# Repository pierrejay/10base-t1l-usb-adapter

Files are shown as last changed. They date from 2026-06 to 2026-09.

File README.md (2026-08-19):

# Single Pair Ethernet 10BASE-T1L USB adapter

A USB ↔ SPE 10BASE-T1L adapter: plug it into any Linux host and get a
standard network interface that speaks Ethernet over a single twisted pair
(long-reach, up to ~1 km, 10 Mbit/s full-duplex). An easy way to give
a laptop, a Raspberry Pi, or an embedded SoC an SPE T1L port for bring-up and
diagnostics.

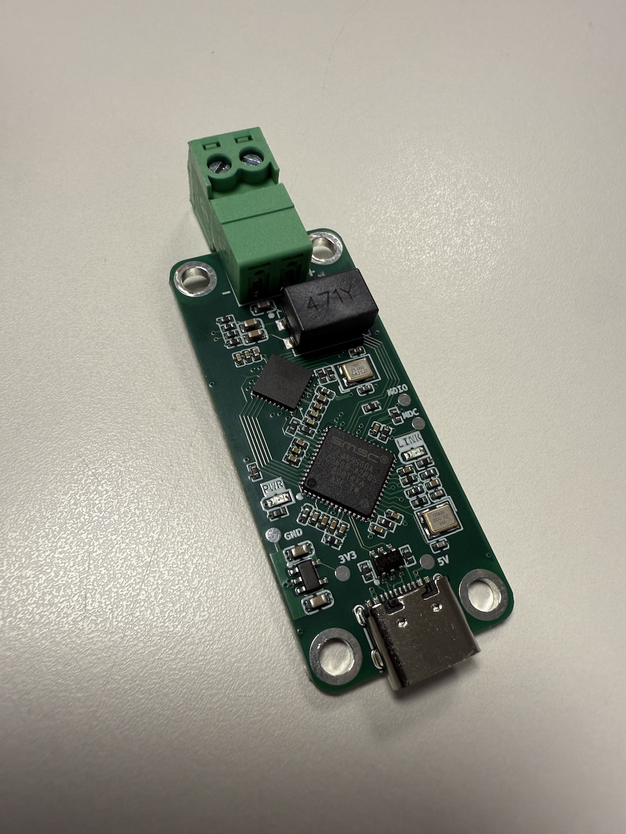
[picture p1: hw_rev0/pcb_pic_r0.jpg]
T1L USB adapter PCB rev 0 — front


## Main components

| Part | Function | Datasheet |
|---|---|---|
| Microchip LAN9500A | USB 2.0 ↔ Ethernet MAC | [product page](https://www.microchip.com/en-us/product/lan9500a) |
| TI DP83TD510E | 10BASE-T1L PHY | [product page](https://www.ti.com/product/DP83TD510E) |

The LAN9500A runs in external PHY (MII) mode: its internal 100M PHY is
bypassed and the MII bus drives the DP83TD510E.

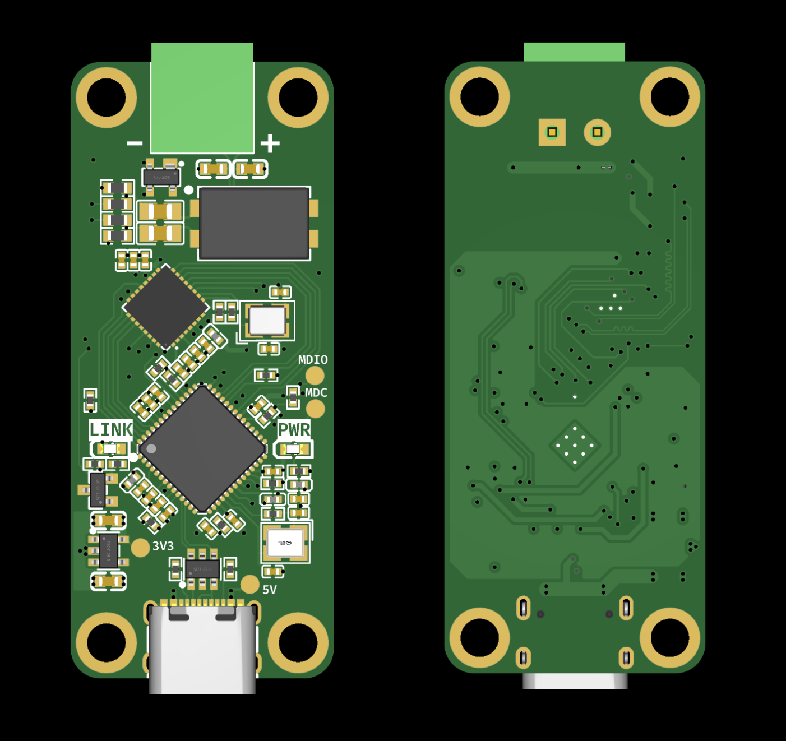
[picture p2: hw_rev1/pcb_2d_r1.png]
T1L USB adapter PCB rev 1 — front and back


## Changelog - Rev 1

- Changed the SPE 24V TVS to a low-cap Ethernet part (`PESD2ETH-AX`) and moved it to
  the PHY side of the CMC for better DP83TD510E front-end protection.
- Updated the termination R/C parts to full 100 V-rated parts for better
  PoDL/cable-fault withstand margin.
- Reworked the cable-side routing, including a copper keepout under the cable
  area up to the CMC (NXP guidelines for UTP).
- Moved LINK LED control from the LAN9500A (unsupported in external PHY mode) to the DP83TD510E.
- Swapped PWR/LINK LED placement to simplify routing.
- Board size is now **51.5 × 22 mm** (Rev 0 was 50 × 22 mm).

## Enclosure

A 3D-printable case STEP model is provided for each of the hardware revisions. It needs a single ⌀2.5×8 mm flat head screw (Plastite or sheet metal/self-tapping screw) to attach the USB-side cap.

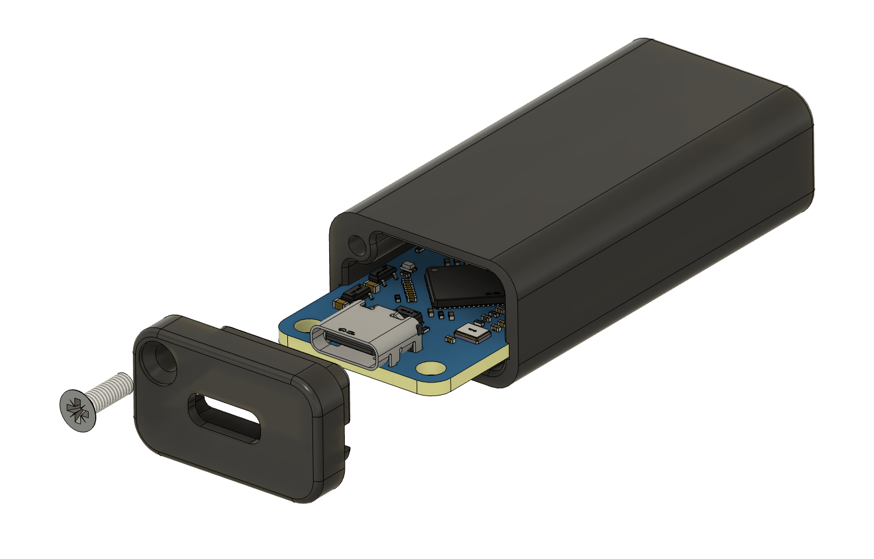
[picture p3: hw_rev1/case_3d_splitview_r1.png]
T1L USB adapter PCB rev 1 — 3D split view with case


## Fabrication

Turnkey at JLCPCB. Import the EasyEDA Pro project, then order PCB + assembly in one shot. 

Rev 1 is also provided as a KiCad project in [`hw_rev1/kicad/`](hw_rev1/kicad/) (KiCad v9.0.7).

**4-layer PCB**: select the `JLC04161H-3313` stackup. The impedance-sensitive 
nets (USB-C D±, the MII bus, the T1L pair) are designed against that specific stackup.

## How it appears to Linux

Two chips, two drivers:

| Chip | Role | Linux driver | Notes |
|---|---|---|---|
| Microchip LAN9500A | USB 2.0 Ethernet MAC | `smsc95xx` | In mainline since forever, same family as the Raspberry Pi's own NIC. Works out of the box. |
| TI DP83TD510E | 10BASE-T1L PHY | `dp83td510` | In mainline since Linux 5.19, but **not always enabled** by distro kernels. Without it the link won't come up. |

When you plug the dongle in, `smsc95xx` enumerates and creates an interface
(`eth0`, `eth1`, … called `ethN` below). The MDIO scan finds the DP83TD510E
at address 0 (PHY ID `0x2000.0181`). **The PHY driver must be present**, or the
PHY falls back to *Generic PHY* and the T1L link never establishes.

> Quick identity check: `lsusb` should show VID `0424` / PID `9e00`.

## OS / driver support

| Host | `smsc95xx` (MAC) | `dp83td510` (PHY) | What to do |
|---|---|---|---|
| **Recent Ubuntu / Debian** (kernel ≥ 6.x) | usually built-in | usually built-in | Works out of the box when the PHY driver is enabled. Cable test (`ethtool --cable-test`) is kernel/driver-version dependent. |
| **Raspberry Pi OS** (Bookworm, ~6.x) | built-in | **absent** on the tested image | Build the PHY driver via DKMS (see below). Validated on Pi 3B+ / 6.12. |
| **Embedded target** (Buildroot / Yocto) | enable `CONFIG_USB_NET_SMSC95XX` | enable `CONFIG_DP83TD510_PHY` | Confirmed working from kernel **6.1 up** with the right driver/config in the BSP. Cable-test support is version-dependent, see the note below. |

> **Cable test on embedded kernels: it depends.** `ethtool --cable-test` needs a
> recent enough `dp83td510`. The 6.1-era driver may predate it, but the driver has
> been updated upstream since, so whether it's there comes down to exactly what
> your BSP ships (YMMV; check case by case). Where it's missing, the TDR/ALCD
> sequence can be driven directly over MDIO instead of through `ethtool`.

### Enabling the PHY driver as DKMS

On stock Raspberry Pi OS (and any host whose kernel doesn't ship `dp83td510`),
build it out-of-tree as a DKMS module so it survives reboots and kernel
updates. See the [`install-dp83td510-dkms.sh`](install-dp83td510-dkms.sh) script
(tested on RPi 3B+, very likely working on RPi 4, TBC for RPi 5).

After installing, unplug and replug the dongle, the PHY binds at USB
enumeration. Then `dmesg | grep -i DP83TD510` should read
`... attached PHY driver` (not `Generic PHY`).

## Quick start - Bring up a link

10BASE-T1L is point-to-point: one end is **master** (drives the clock), the other
**slave**. The DP83TD510E supports BASE-T1 auto-negotiation (IEEE 802.3cg) and
the dongle defaults to **preferred slave** so against a gateway, switch or media
converter that is master, the roles resolve automatically and the dongle will
not try to take master.

On a managed host (NetworkManager, `dhcpcd`, `systemd-networkd`, ...), the
interface may already be up and configured when the dongle is plugged in. Check
first, then bring it up manually only if it is still down:

```sh
ip link show ethN
sudo ip link set ethN up   # only if the interface is still DOWN / unmanaged
ethtool ethN               # Link detected: yes, Speed 10Mb/s, Duplex Full
sudo dhclient ethN         # only if DHCP was not already handled
```

A working link reads `10baseT1L/Full` and `Link detected: yes`.

You only need to force a role when auto-negotiation can't settle it: two
dongles back to back (both default to slave), or a peer running with AN disabled
/ a fixed role you have to match:

```sh
sudo ethtool -s ethN master-slave forced-master   # or forced-slave, to match the peer
```

## Throughput sanity check

Bench test: `iperf3` between a Mac and a Linux target, through this dongle and a
WAGO 852-1705 gateway. TCP throughput is stable in both directions at about line
rate:

- **downlink:** ~9.4 Mbit/s effective, with 0 retransmits in the captured run.
- **uplink:** ~9.4 Mbit/s effective.

For a 10 Mbit/s T1L link, that's the expected ceiling once Ethernet/IP/TCP
overhead is counted.

## Diagnostics with stock tools

`ethtool` and [`phytool`](https://github.com/wkz/phytool) cover the essentials —
no project-specific software needed. `ethtool` ships with every distro; `phytool`
often isn't packaged (e.g. on Raspberry Pi OS), but it builds in seconds:

```sh
git clone https://github.com/wkz/phytool && make -C phytool
sudo cp phytool/phytool /usr/local/bin/   # or anywhere on your PATH
```

### Link, speed, master/slave

```sh
ethtool ethN
#   Speed: 10Mb/s
#   Duplex: Full
#   Supported link modes:   10baseT1L/Full
#   master-slave cfg: forced master      (or preferred slave)
#   Link detected: yes
```

### Reliable link status (PHY_STS)

The Clause-22 BMSR link bit is latch-low on this PHY and gives timing false
negatives. The robust source is the vendor `PHY_STS` register (Clause 22, reg
`0x10`), bit 0 = link up:

```sh
phytool read ethN/0/0x10        # bit0 set => link up
```

### Signal quality (SQI / MSE)

The DP83TD510E reports a Mean-Square-Error metric (MMD VEND2 `0x1F`, reg
`0xA85`); lower MSE = cleaner signal = higher SQI (0–7). Native Clause-45 access
returns `EOPNOTSUPP` on the `smsc95xx` MDIO bus, so read it the way the kernel
does, **Clause-22-indirect** via the MMD access registers (`0x0D`/`0x0E`):

```sh
phytool write ethN/0/0x0d 0x001f   # MMD_CTRL: function=address, devad=0x1F
phytool write ethN/0/0x0e 0x0a85   # MMD_DATA: register = MSE_DETECT
phytool write ethN/0/0x0d 0x401f   # MMD_CTRL: function=data, devad=0x1F
phytool read  ethN/0/0x0e          # -> MSE, e.g. 0x001b
```

Reference (good link, on the bench): MSE `0x001b` → SQI 7/7, SNR ≈ 35 dB. The
SQI thresholds live in the `dp83td510` driver / TI datasheet.

### Cable test (TDR / ALCD)

On a kernel whose `dp83td510` includes cable test (≥ 6.x):

```sh
ethtool --cable-test ethN
```

- **Link up** → ALCD reports cable **length**.
- **Link down** → TDR reports a **fault** (open / short) and a location.

> ⚠ **Distance is not trustworthy out of the box.** The fault *type* (open vs
> short) is reliable; the *distance* is raw and the kernel's ×100 scaling looks
> wrong at short range (it reports ~25 m for a meter-ish-long cable). Real distance
> needs per-cable calibration (TI app note SNLA364).

The raw-graph form (`--cable-test-tdr`) is not supported by this driver.

## License

Licensed under `CERN-OHL-P-2.0` (cf. LICENSE file)

© Pierre Jay 2026

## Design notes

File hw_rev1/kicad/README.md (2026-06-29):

# KiCad

This KiCad project was imported from EasyEDA and is maintained with KiCad v9.0.7.

EasyEDA 3D model files are not versioned here. They should be regenerated locally with `easyeda2kicad` and the sync helper.

## Restore 3D Models

Requirements:

- `easyeda2kicad` installed and available in `PATH`
- local central library in `~/Documents/KiCad/easyeda2kicad`

From this directory:

```bash
EASYEDA_LIBRARY="$HOME/Documents/KiCad/easyeda2kicad"

./sync_easyeda_models.py . \
  --library "$EASYEDA_LIBRARY" \
  --pull-footprint-models
```

The script copies only the required models into `EASYEDA_MODELS/`, applies known 3D alignment fixes, and fetches missing parts through `easyeda2kicad` when possible.

## After 3D Alignment Fixes

If a model is manually realigned in KiCad, push the correction back to the local library:

```bash
EASYEDA_LIBRARY="$HOME/Documents/KiCad/easyeda2kicad"

./sync_easyeda_models.py . \
  --library "$EASYEDA_LIBRARY" \
  --push-to-library
```

Other projects can then reuse those fixes with `--pull-footprint-models`.

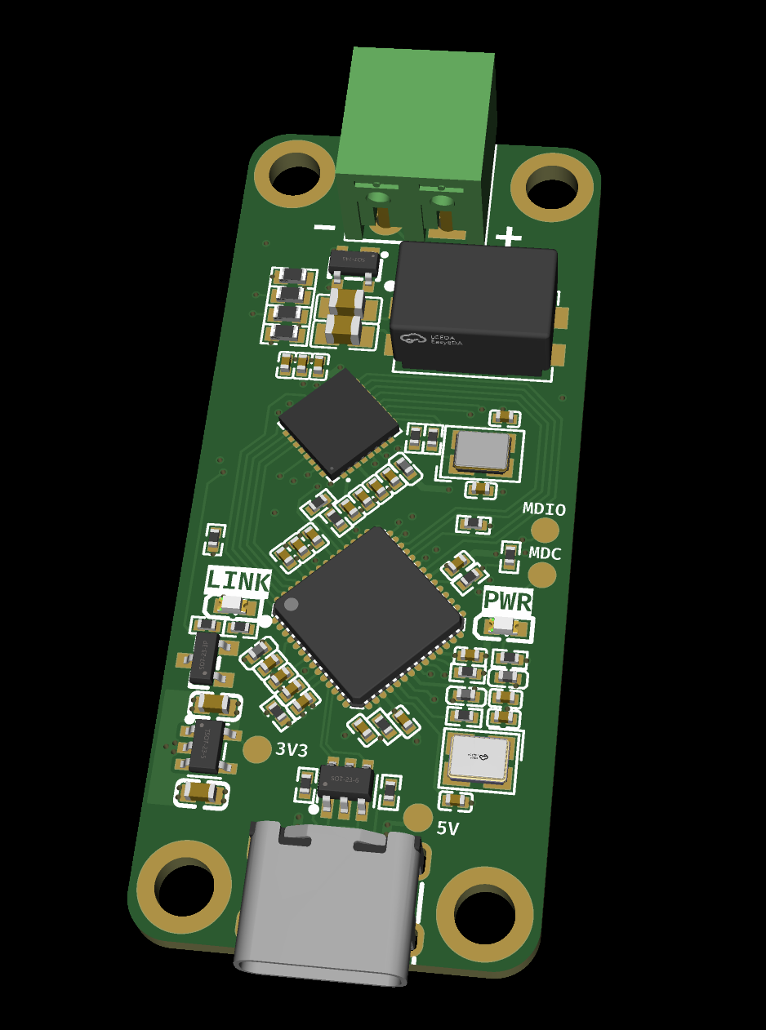
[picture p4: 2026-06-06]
hw_rev1/pcb_3d_r1.png

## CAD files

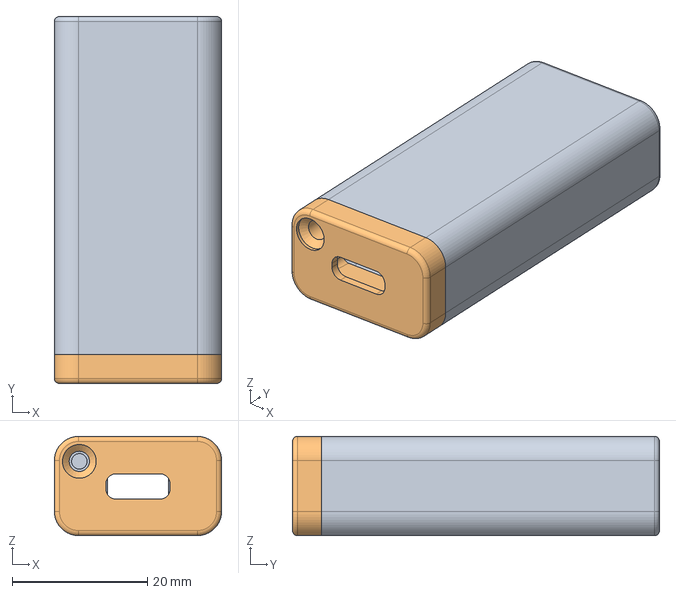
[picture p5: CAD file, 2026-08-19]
hw_rev1/spe-T1L_usb_adapter_case_r1.step
24.8 x 54.3 x 14.7 mm

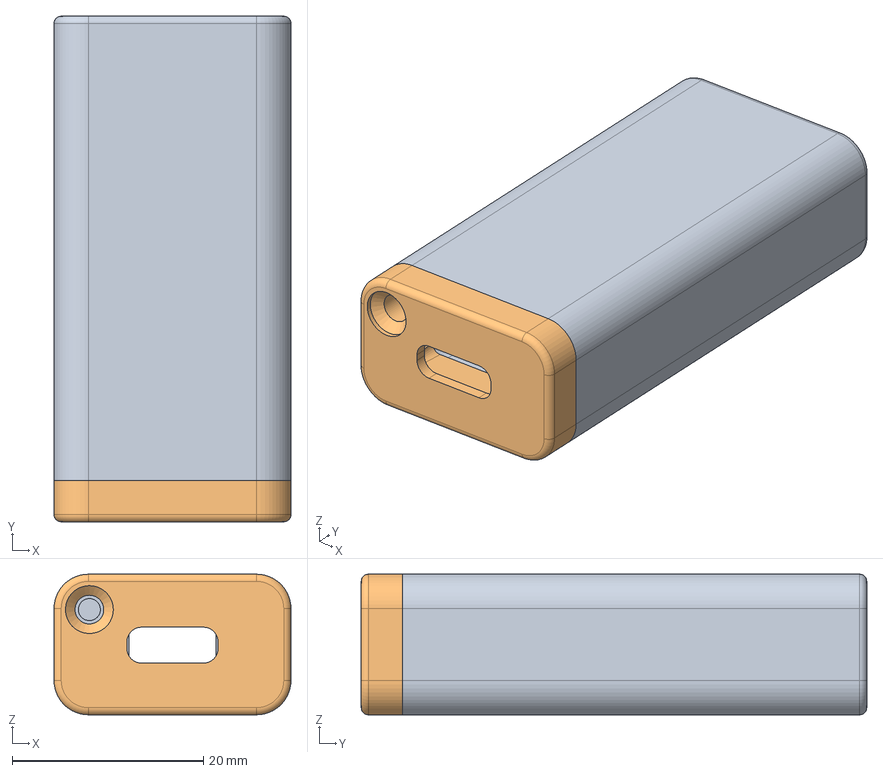
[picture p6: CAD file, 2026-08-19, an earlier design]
hw_rev0/spe-T1L_usb_adapter_case_r0.step
24.8 x 52.8 x 14.7 mm

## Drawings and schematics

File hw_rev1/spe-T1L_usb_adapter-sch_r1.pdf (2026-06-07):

# USB-Ethernet MAC

# SPE termination

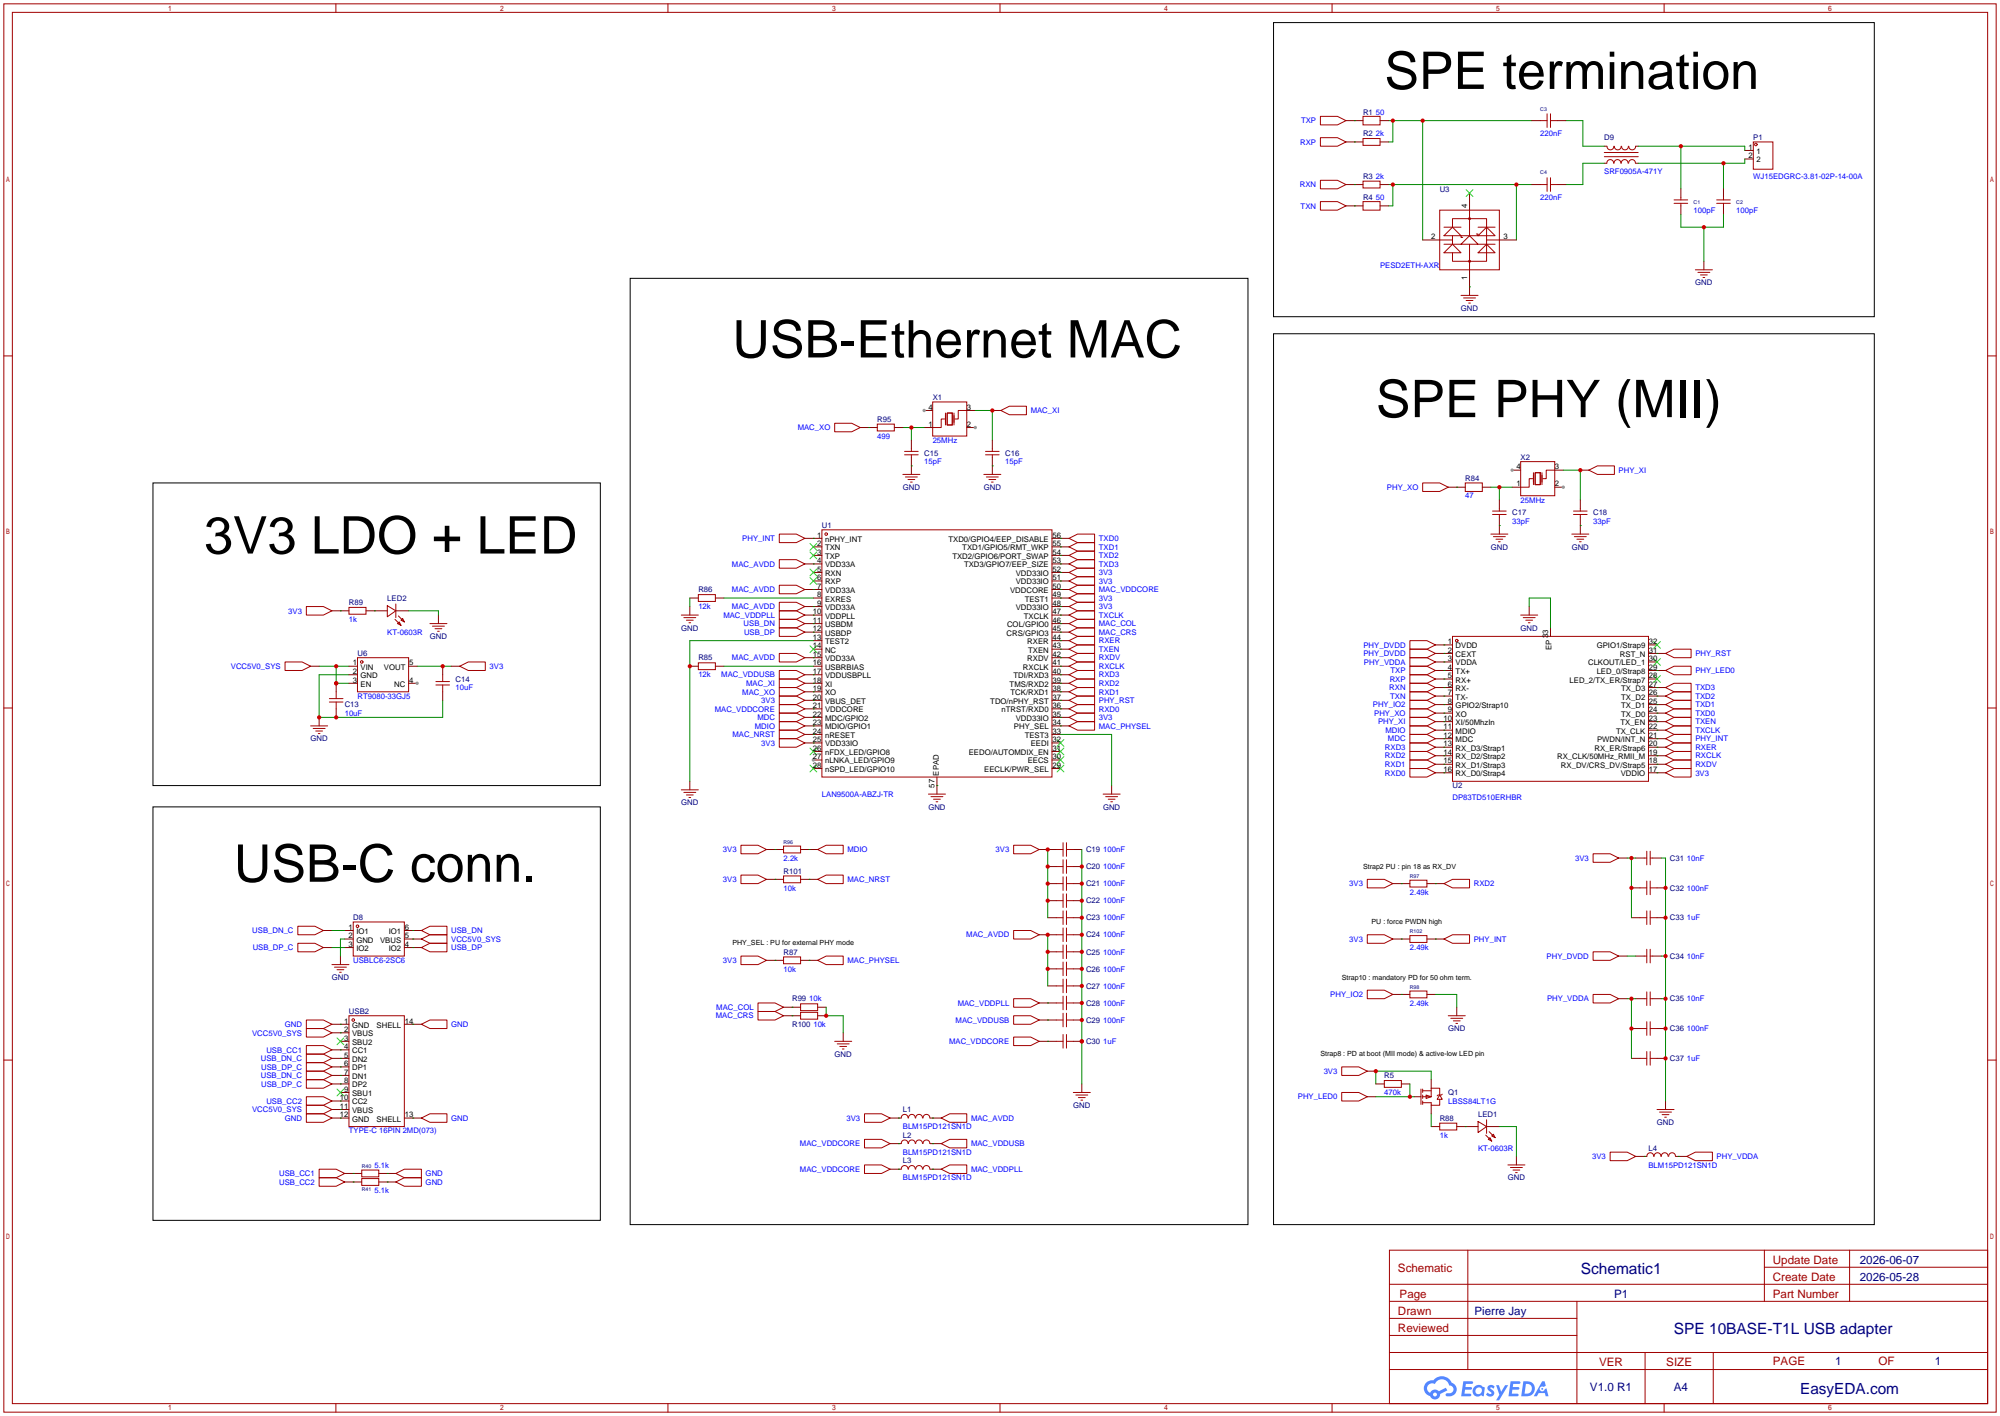
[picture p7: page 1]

PU : force PWDN high

PHY_SEL : PU for external PHY mode

Strap10 : mandatory PD for 50 ohm term.
PHY_IO2

Strap8 : PD at boot (MII mode) & active-low LED pin

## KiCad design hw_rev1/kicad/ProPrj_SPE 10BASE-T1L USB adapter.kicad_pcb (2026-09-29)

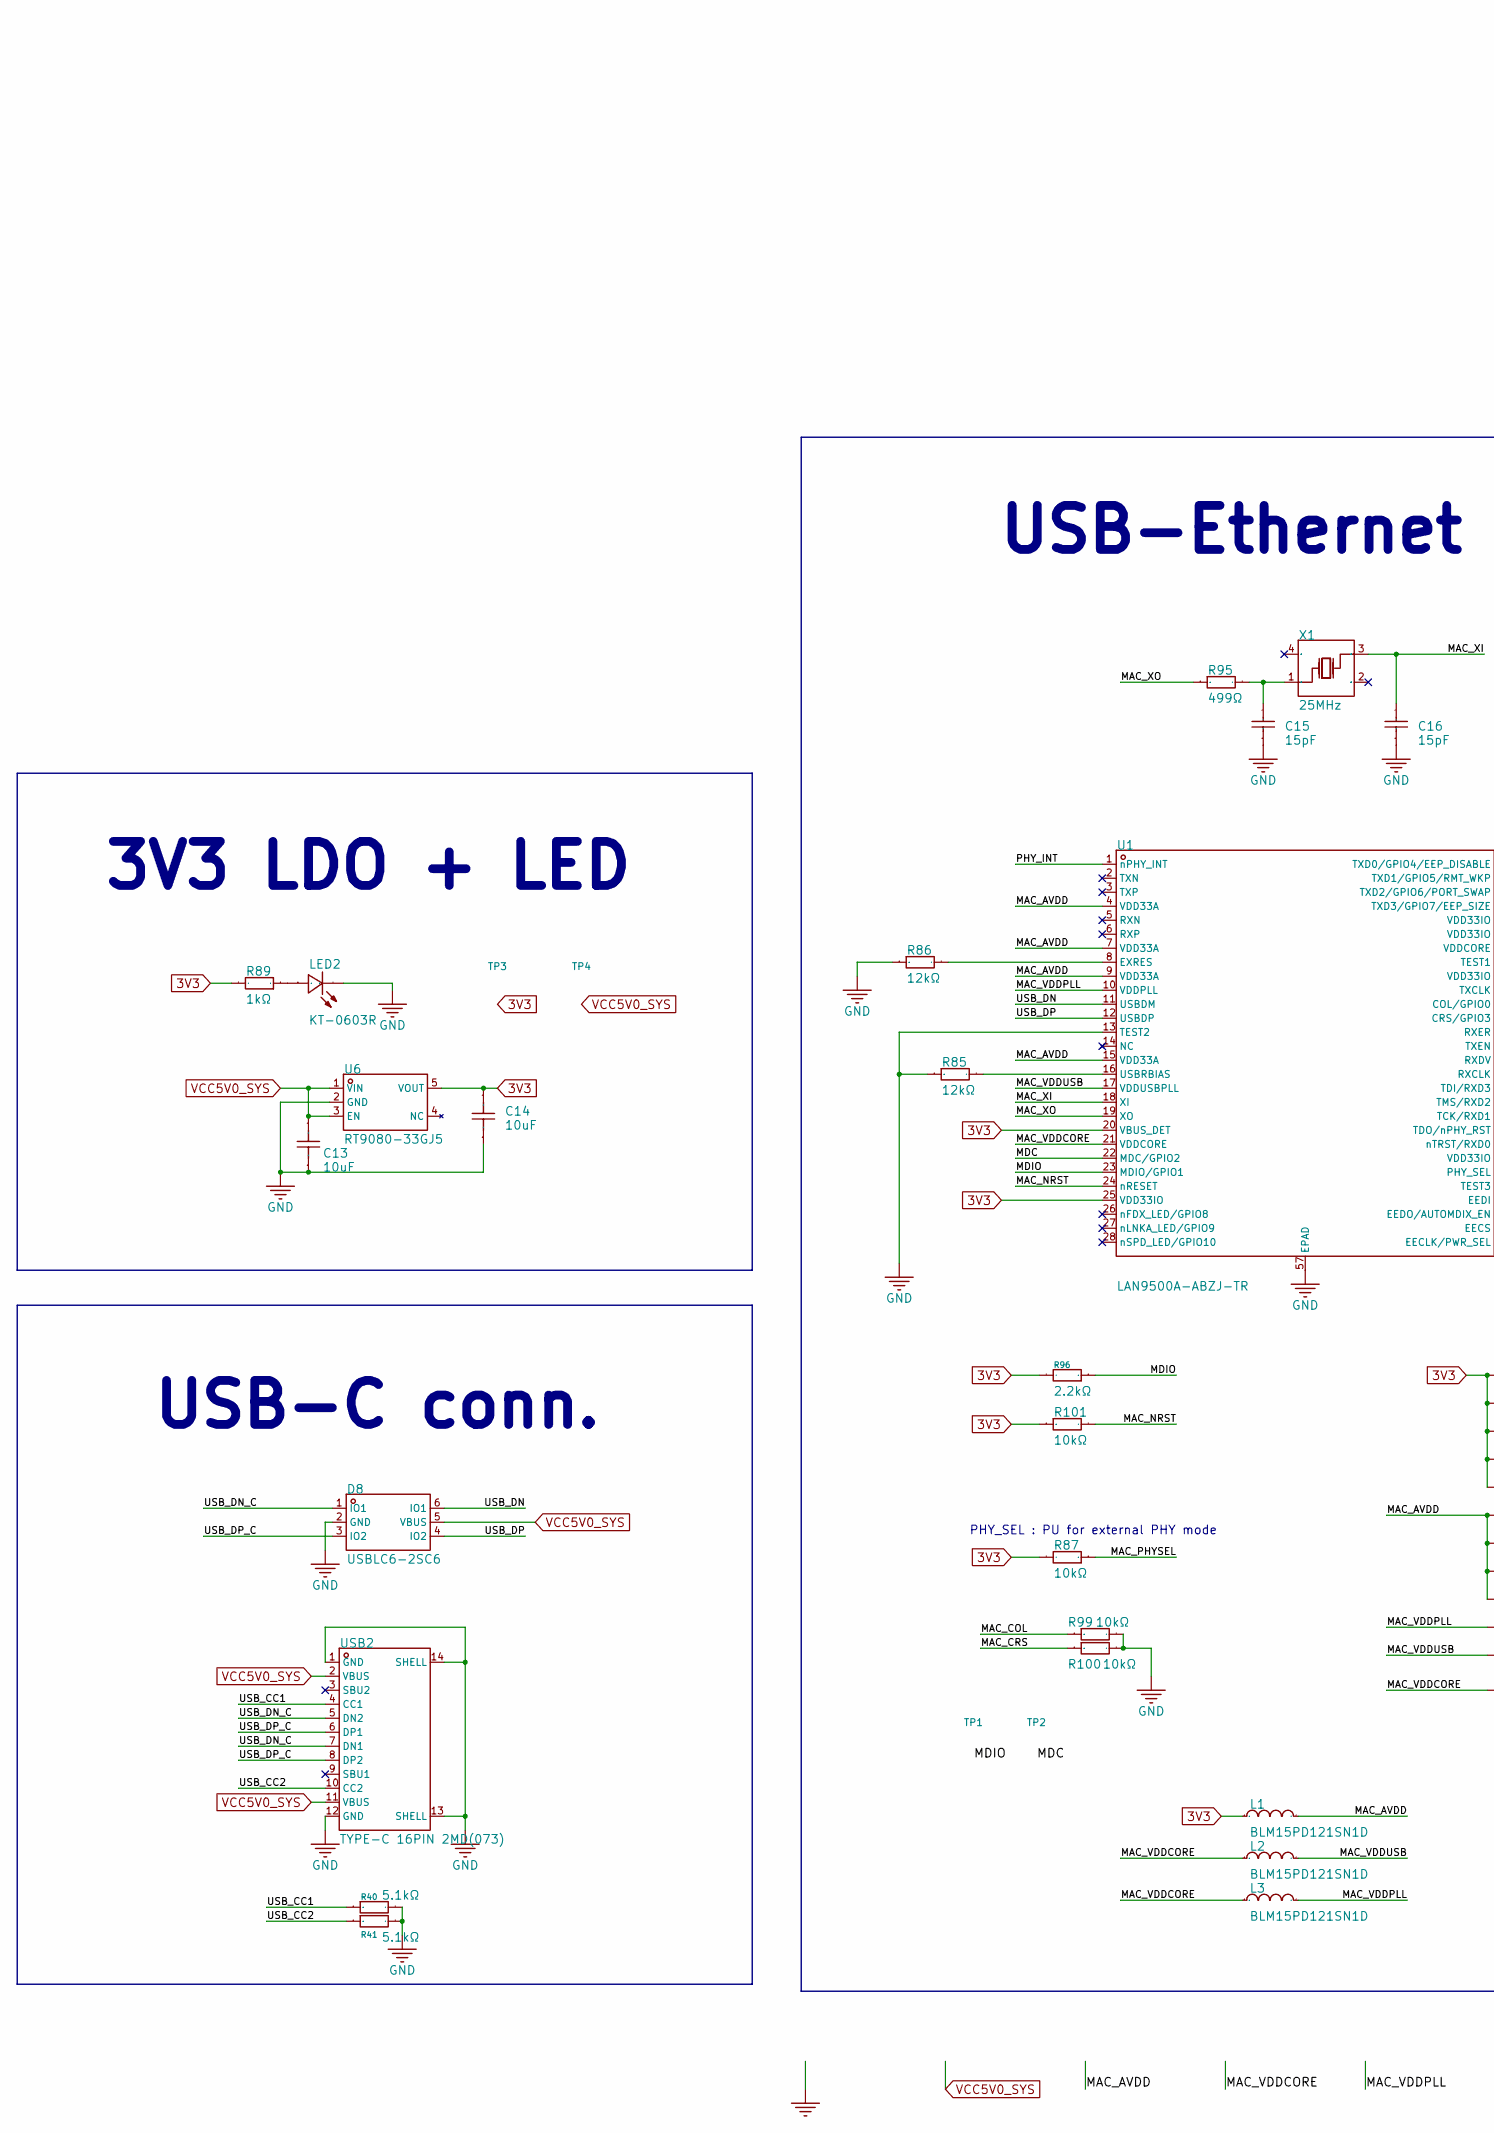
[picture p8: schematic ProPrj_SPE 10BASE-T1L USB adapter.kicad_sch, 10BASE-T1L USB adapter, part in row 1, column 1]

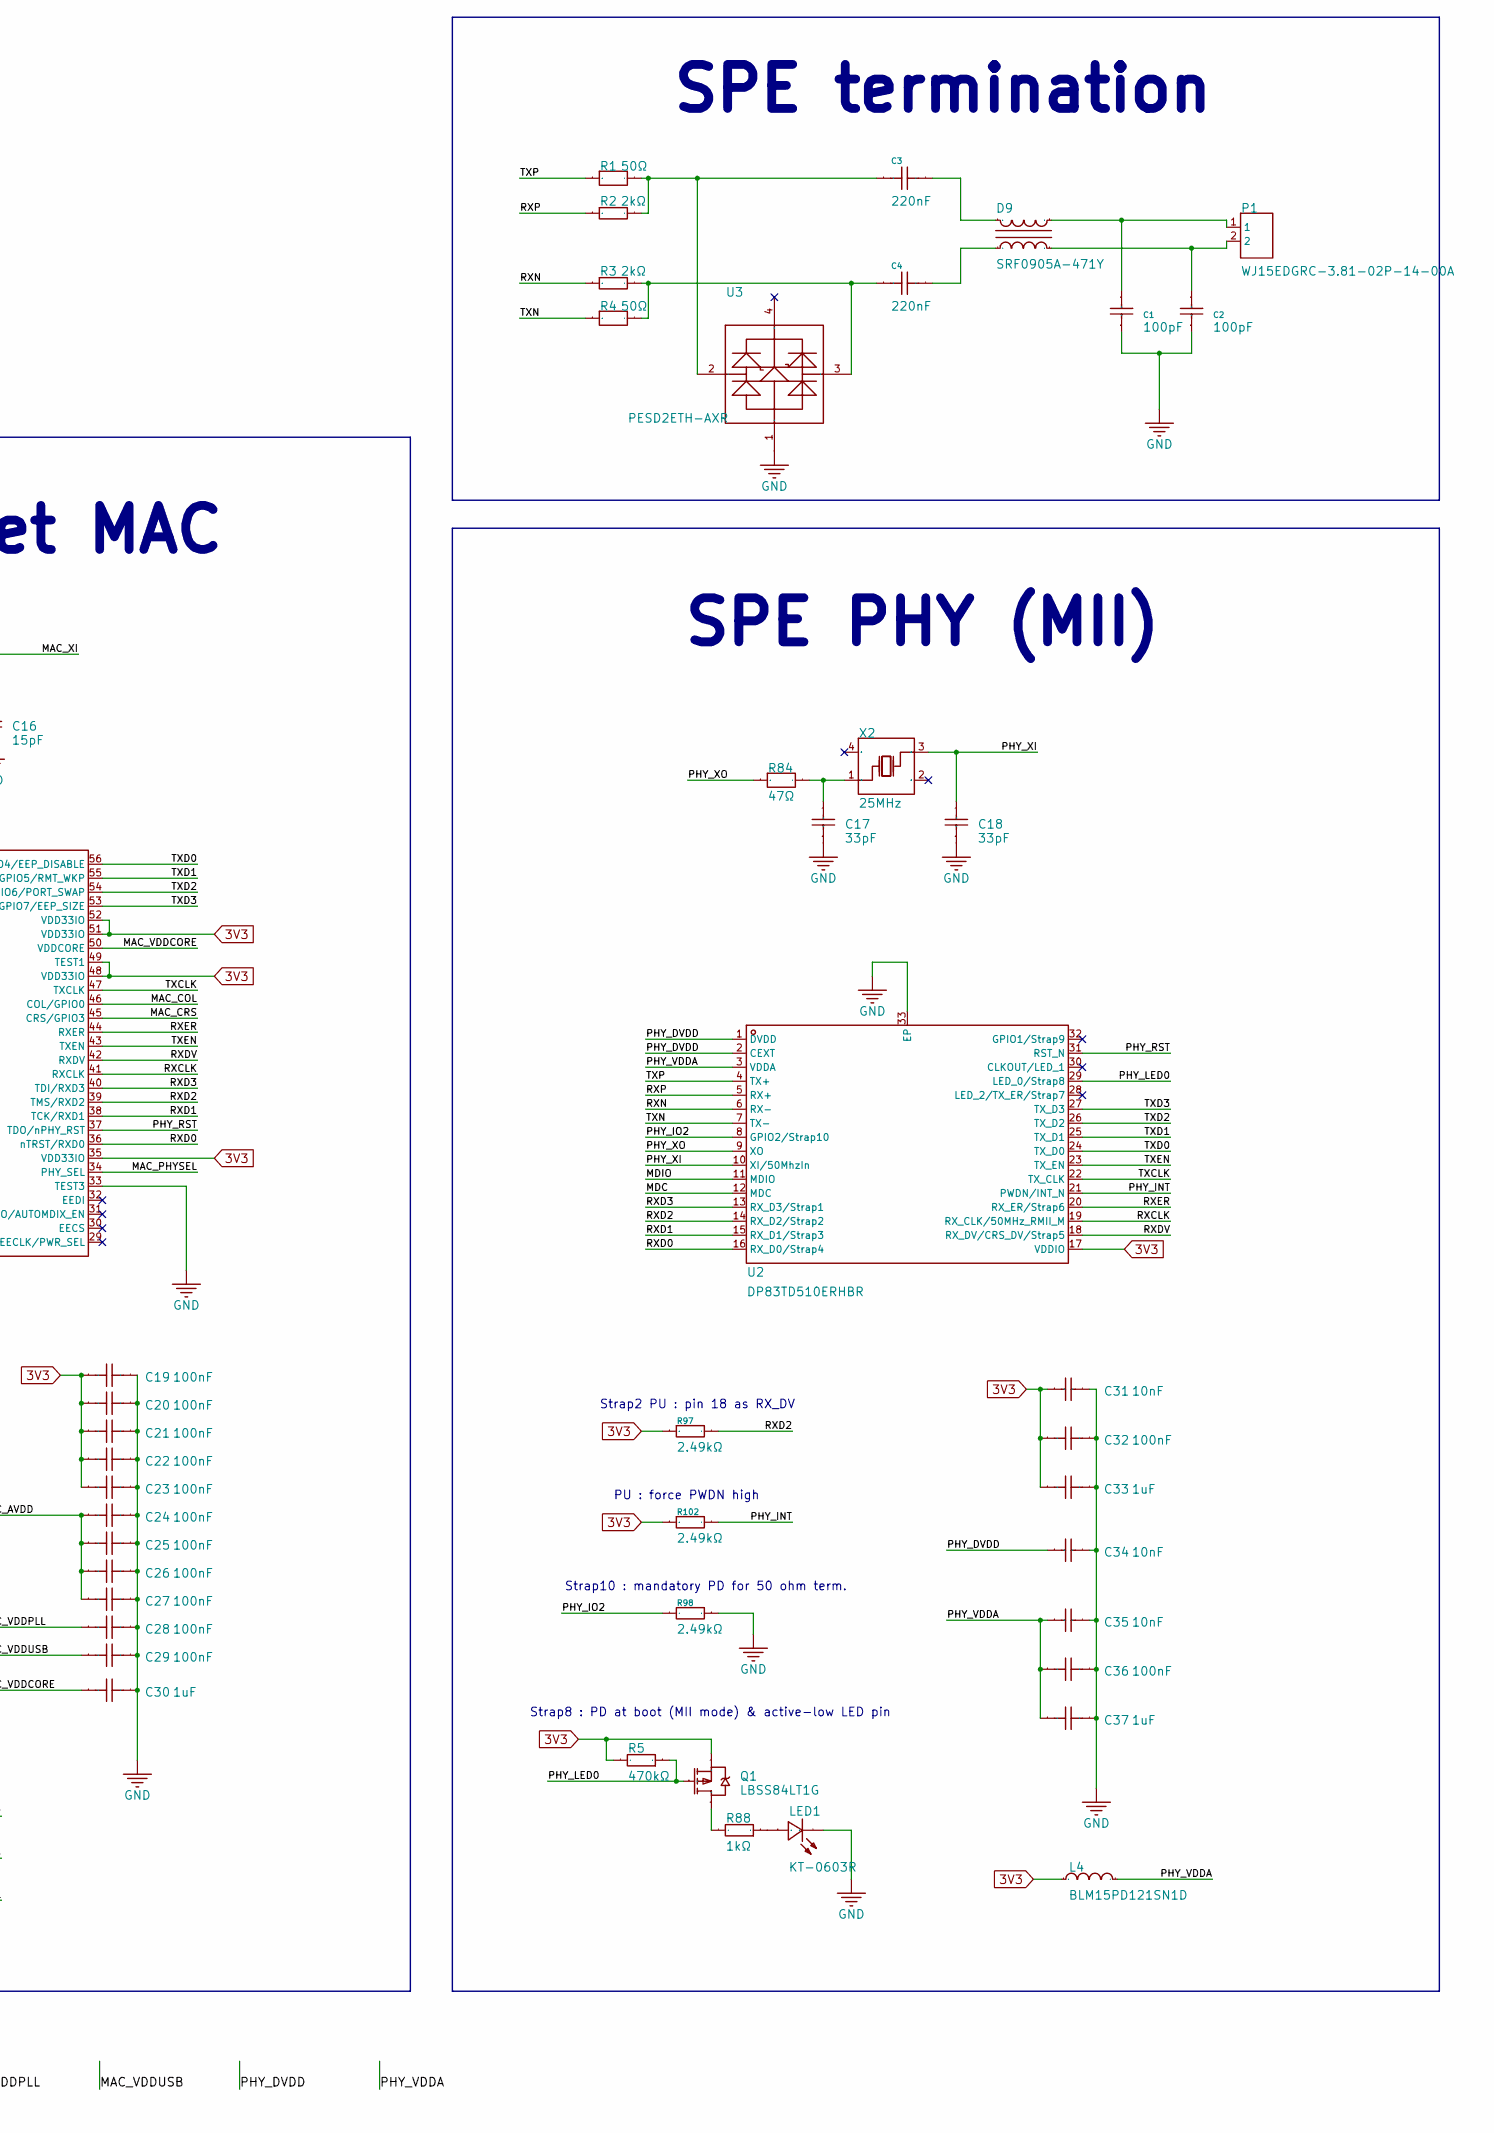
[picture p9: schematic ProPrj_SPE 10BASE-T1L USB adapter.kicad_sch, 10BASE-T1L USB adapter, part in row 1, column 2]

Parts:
C1, C2: 100pF; C0603; Manufacturer Part CC0603JRNPO0BN101; LCSC Part Name 100pF ±5% 100V
C3, C4: 220nF; C0805; Manufacturer Part CC0805KKX7R0BB224; LCSC Part Name 220nF ±10% 100V
C13, C14: 10uF; C0603; Manufacturer Part CL10A106MQ8NNNC; LCSC Part Name 10uF ±20% 6.3V
C15, C16: 15pF; C0402; Manufacturer Part 0402CG150J500NT; LCSC Part Name 15pF ±5% 50V
C17, C18: 33pF; C0402; Manufacturer Part 0402CG330J500NT; LCSC Part Name 33pF ±5% 50V
C19, C20, C21, C22, C23, C24, C25, C26, C27, C28, C29, C32, C36: 100nF; C0402; Manufacturer Part CL05B104KO5NNNC; LCSC Part Name 100nF ±10% 16V
C30, C33, C37: 1uF; C0402; Manufacturer Part CL05A105KA5NQNC; LCSC Part Name 1uF ±10% 25V
C31, C34, C35: 10nF; C0402; Manufacturer Part CL05B103KB5NNNC; LCSC Part Name 10nF ±10% 50V
D8: USBLC6-2SC6; SOT-23-6_L2.9-W1.6-P0.95-LS2.8-BL; Manufacturer Part USBLC6-2SC6; LCSC Part Name ESD，可防30kV静电
D9: SRF0905A-471Y; FILTER-SMD_4P-L9.2-W6.0-TL-A; Manufacturer Part SRF0905A-471Y; LCSC Part Name 两路 共模滤波器 阻抗1000Ω@20MHz
L1, L2, L3, L4: BLM15PD121SN1D; L0402; Manufacturer Part BLM15PD121SN1D; LCSC Part Name 单路 0402磁珠 阻抗120Ω@100MHz
LED1, LED2: KT-0603R; LED-SMD_L1.6-W0.8-R-RD; Manufacturer Part KT-0603R; LCSC Part Name 0603 红灯 高亮
P1: WJ15EDGRC-3.81-02P-14-00A; CONN-TH_2P-P3.81_WJ15EDGRC-3.81-2P; Manufacturer Part WJ15EDGRC-3.81-02P-14-00A; LCSC Part Name 卡扣固定 1x2P 3.81mm 排数:1 每排P数:2
Q1: LBSS84LT1G; SOT-23_L2.9-W1.3-P1.90-LS2.4-BR; Manufacturer Part LBSS84LT1G; LCSC Part Name 1个P沟道 耐压:50V 电流:0.13A
R1, R4: 50Ω; R0603; Manufacturer Part RT0603BRE0750RL; LCSC Part Name 薄膜电阻 50Ω ±0.1% 100mW
R2, R3: 2kΩ; R0603; Manufacturer Part 0603WAF2001T5E; LCSC Part Name 2kΩ ±1% 100mW 厚膜电阻
R5: 470kΩ; R0402; Manufacturer Part 0402WGF4703TCE; LCSC Part Name 470kΩ ±1% 62.5mW 厚膜电阻
R40, R41: 5.1kΩ; R0402; Manufacturer Part 0402WGF5101TCE; LCSC Part Name 5.1kΩ ±1% 62.5mW 厚膜电阻
R84: 47Ω; R0402; Manufacturer Part FRC0402F47R0TS; LCSC Part Name 47Ω ±1% 62.5mW 厚膜电阻
R85, R86: 12kΩ; R0402; Manufacturer Part 0402WGF1202TCE; LCSC Part Name 12kΩ ±1% 62.5mW 厚膜电阻
R87, R99, R100, R101: 10kΩ; R0402; Manufacturer Part 0402WGF1002TCE; LCSC Part Name 10kΩ ±1% 62.5mW 厚膜电阻
R88, R89: 1kΩ; R0402; Manufacturer Part 0402WGF1001TCE; LCSC Part Name 1kΩ ±1% 62.5mW 厚膜电阻
R95: 499Ω; R0402; Manufacturer Part 0402WGF4990TCE; LCSC Part Name 499Ω ±1% 62.5mW 厚膜电阻
R96: 2.2kΩ; R0402; Manufacturer Part 0402WGF2201TCE; LCSC Part Name 2.2kΩ ±1% 62.5mW 厚膜电阻
R97, R98, R102: 2.49kΩ; R0402; Manufacturer Part 0402WGF2491TCE; LCSC Part Name 2.49kΩ ±1% 62.5mW 厚膜电阻
TP1: TestPoint; Pad_e105
TP2: TestPoint; Pad_e106
TP3: TestPoint; Pad_e107
TP4: TestPoint; Pad_e108
U1: LAN9500A-ABZJ-TR; QFN-56_L8.0-W8.0-P0.50-TL-EP6.1; Manufacturer Part LAN9500A-ABZJ-TR; LCSC Part Name LAN950x USB 2.0 到 10/100 以太网控制器
U2: DP83TD510ERHBR; HVQFN-32_L5.0-W5.0-P0.50-TL-EP2.1; Manufacturer Part DP83TD510ERHBR; LCSC Part Name Ultra Low Power 802.3cg 10Base-T1L 10M 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
U3: PESD2ETH-AXR; SOT-143_L2.9-W1.3-P1.92-LS2.3-BL; Manufacturer Part PESD2ETH-AXR; LCSC Part Name ESD 5V截止 峰值浪涌电流：4A@8/20us
U6: RT9080-33GJ5; TSOT-23-5_L2.9-W1.6-P0.95-LS2.8-BL; Manufacturer Part RT9080-33GJ5; LCSC Part Name 静态电流2μA，输出电流600mA的低压差线性稳压器
USB2: TYPE-C 16PIN 2MD(073); USB-C-SMD_TYPE-C-6PIN-2MD-073; Manufacturer Part TYPE-C 16PIN 2MD(073); LCSC Part Name Type-C 母 卧贴
X1: 25MHz; CRYSTAL-SMD_4P-L3.2-W2.5-BL; Manufacturer Part X322525MOB4SI; LCSC Part Name YSX321SL 25MHZ 4P 3225 12PF ±10PPM -40~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
X2: 25MHz; CRYSTAL-SMD_4P-L3.2-W2.5-BL-2; Manufacturer Part X322525MSB4SI; LCSC Part Name YSX321SL 25MHZ 4P 3225 20PF ±10PPM -40~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

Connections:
3V3: C14.2, C19.1, C20.1, C21.1, C22.1, C23.1, C31.1, C32.1, C33.1, L1.1, L4.1, Q1.2 (S), R5.2, R87.2, R89.2, R96.2, R97.1, R101.1, R102.1, TP3.1 (1_1), U1.20 (VBUS_DET), U1.25 (VDD33IO), U1.35 (VDD33IO), U1.48 (VDD33IO), U1.49 (TEST1), U1.51 (VDD33IO), U1.52 (VDD33IO), U2.17 (VDDIO), U6.5 (VOUT)
/MAC_AVDD: C24.1, C25.1, C26.1, C27.1, L1.2, U1.4 (VDD33A), U1.7 (VDD33A), U1.9 (VDD33A), U1.15 (VDD33A)
/MAC_COL: R99.1, U1.46 (COL/GPIO0)
/MAC_CRS: R100.1, U1.45 (CRS/GPIO3)
/MAC_NRST: R101.2, U1.24 (nRESET)
/MAC_PHYSEL: R87.1, U1.34 (PHY_SEL)
/MAC_VDDCORE: C30.1, L2.1, L3.1, U1.21 (VDDCORE), U1.50 (VDDCORE)
/MAC_VDDPLL: C28.1, L3.2, U1.10 (VDDPLL)
/MAC_VDDUSB: C29.1, L2.2, U1.17 (VDDUSBPLL)
/MAC_XI: C16.2, U1.18 (XI), X1.3 (OSC2)
/MAC_XO: R95.1, U1.19 (XO)
/MDC: TP2.1 (1_1), U1.22 (MDC/GPIO2), U2.12 (MDC)
/MDIO: R96.1, TP1.1 (1_1), U1.23 (MDIO/GPIO1), U2.11 (MDIO)
/PHY_DVDD: C34.1, U2.1 (DVDD), U2.2 (CEXT)
/PHY_INT: R102.2, U1.1 (nPHY_INT), U2.21 (PWDN/INT_N)
/PHY_IO2: R98.2, U2.8 (GPIO2/Strap10)
/PHY_LED0: Q1.1 (G), R5.1, U2.29 (LED_0/Strap8)
/PHY_RST: U1.37 (TDO/nPHY_RST), U2.31 (RST_N)
/PHY_VDDA: C35.1, C36.1, C37.1, L4.2, U2.3 (VDDA)
/PHY_XI: C18.2, U2.10 (XI/50MhzIn), X2.3 (OSC2)
/PHY_XO: R84.1, U2.9 (XO)
/RXCLK: U1.41 (RXCLK), U2.19 (RX_CLK/50MHz_RMII_M)
/RXD0: U1.36 (nTRST/RXD0), U2.16 (RX_D0/Strap4)
/RXD1: U1.38 (TCK/RXD1), U2.15 (RX_D1/Strap3)
/RXD2: R97.2, U1.39 (TMS/RXD2), U2.14 (RX_D2/Strap2)
/RXD3: U1.40 (TDI/RXD3), U2.13 (RX_D3/Strap1)
/RXDV: U1.42 (RXDV), U2.18 (RX_DV/CRS_DV/Strap5)
/RXER: U1.44 (RXER), U2.20 (RX_ER/Strap6)
/RXN: R3.1, U2.6 (RX-)
/RXP: R2.1, U2.5 (RX+)
/TXCLK: U1.47 (TXCLK), U2.22 (TX_CLK)
/TXD0: U1.56 (TXD0/GPIO4/EEP_DISABLE), U2.24 (TX_D0)
/TXD1: U1.55 (TXD1/GPIO5/RMT_WKP), U2.25 (TX_D1)
/TXD2: U1.54 (TXD2/GPIO6/PORT_SWAP), U2.26 (TX_D2)
/TXD3: U1.53 (TXD3/GPIO7/EEP_SIZE), U2.27 (TX_D3)
/TXEN: U1.43 (TXEN), U2.23 (TX_EN)
/TXN: R4.1, U2.7 (TX-)
/TXP: R1.1, U2.4 (TX+)
/USB_CC1: R40.1, USB2.4 (CC1)
/USB_CC2: R41.1, USB2.10 (CC2)
/USB_DN: D8.6 (IO1), U1.11 (USBDM)
/USB_DN_C: D8.1 (IO1), USB2.5 (DN2), USB2.7 (DN1)
/USB_DP: D8.4 (IO2), U1.12 (USBDP)
/USB_DP_C: D8.3 (IO2), USB2.6 (DP1), USB2.8 (DP2)
GND: C1.1, C2.1, C13.1, C14.1, C15.1, C16.1, C17.1, C18.1, C19.2, C20.2, C21.2, C22.2, C23.2, C24.2, C25.2, C26.2, C27.2, C28.2, C29.2, C30.2, C31.2, C32.2, C33.2, C34.2, C35.2, C36.2, C37.2, D8.2 (GND), LED1.2 (K), LED2.2 (K), R40.2, R41.2, R85.1, R86.1, R98.1, R99.2, R100.2, U1.13 (TEST2), U1.33 (TEST3), U1.57 (EPAD), U2.33 (EP), U3.1, U6.2 (GND), USB2.1 (GND), USB2.12 (GND), USB2.13 (SHELL), USB2.14 (SHELL)
unnamed: C1.2, D9.4, P1.1
unnamed: C2.2, D9.3, P1.2
unnamed: C3.1, R1.2, R2.2, U3.2
unnamed: C3.2, D9.1
unnamed: C4.1, R3.2, R4.2, U3.3
unnamed: C4.2, D9.2
unnamed: LED1.1 (A), R88.1
unnamed: LED2.1 (A), R89.1
unnamed: Q1.3 (D), R88.2
unnamed: R86.2, U1.8 (EXRES)
unnamed: R85.2, U1.16 (USBRBIAS)
unnamed: C15.2, R95.2, X1.1 (OSC1)
unnamed: C17.2, R84.2, X2.1 (OSC1)
VCC5V0_SYS: C13.2, D8.5 (VBUS), TP4.1 (1_1), U6.1 (VIN), U6.3 (EN), USB2.2 (VBUS), USB2.11 (VBUS)

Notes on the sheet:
SPE PHY (MII)
PHY_SEL : PU for external PHY mode
Strap10 : mandatory PD for 50 ohm term.
Strap8 : PD at boot (MII mode) & active-low LED pin
3V3 LDO + LED
USB-Ethernet MAC
PU : force PWDN high
SPE termination
Strap2 PU : pin 18 as RX_DV
USB-C conn.

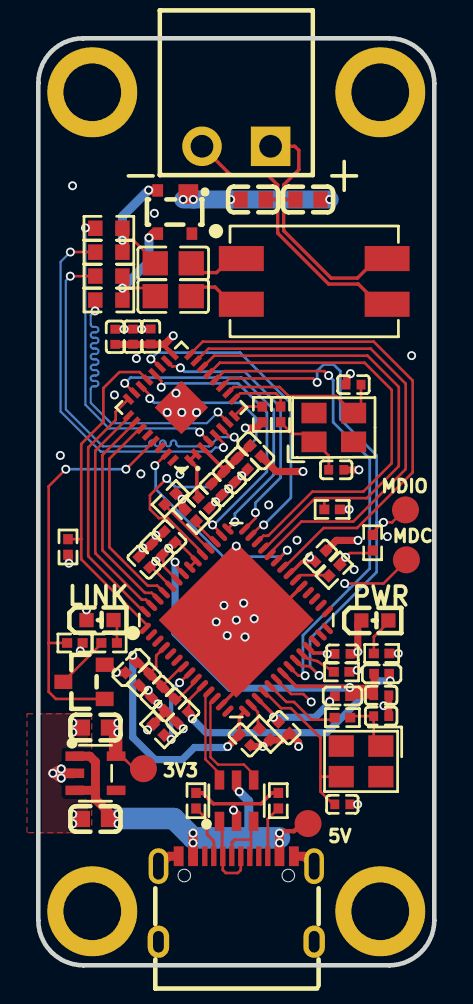
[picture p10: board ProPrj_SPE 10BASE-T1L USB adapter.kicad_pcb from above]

Board: 4 copper layers, 22.0 x 51.5 mm, 71 parts (0 on the bottom side), 59 nets.

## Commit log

2026-06-06 Update rev1 schematic to remove screenshots from vendor datasheets
2026-06-07 Fix LINK LED PMOS
2026-06-07 Clean up schematic drawing
2026-06-29 Add KiCad files
    [ProPrj_SPE 10BASE-T1L USB adapter.kicad_pcb, ProPrj_SPE 10BASE-T1L USB adapter.kicad_sch]
2026-08-19 Add enclosure STEP models
    [spe-T1L_usb_adapter_case_r0.step, spe-T1L_usb_adapter_case_r1.step]
2026-08-23 Add KiCad design rules file + cleanup DRC
    [ProPrj_SPE 10BASE-T1L USB adapter.kicad_pcb]
2026-09-05 Cleanup KiCad schematic
    [ProPrj_SPE 10BASE-T1L USB adapter.kicad_pcb, ProPrj_SPE 10BASE-T1L USB adapter.kicad_sch]
2026-09-29 Fix KiCad solder paste mask
    [ProPrj_SPE 10BASE-T1L USB adapter.kicad_pcb]
